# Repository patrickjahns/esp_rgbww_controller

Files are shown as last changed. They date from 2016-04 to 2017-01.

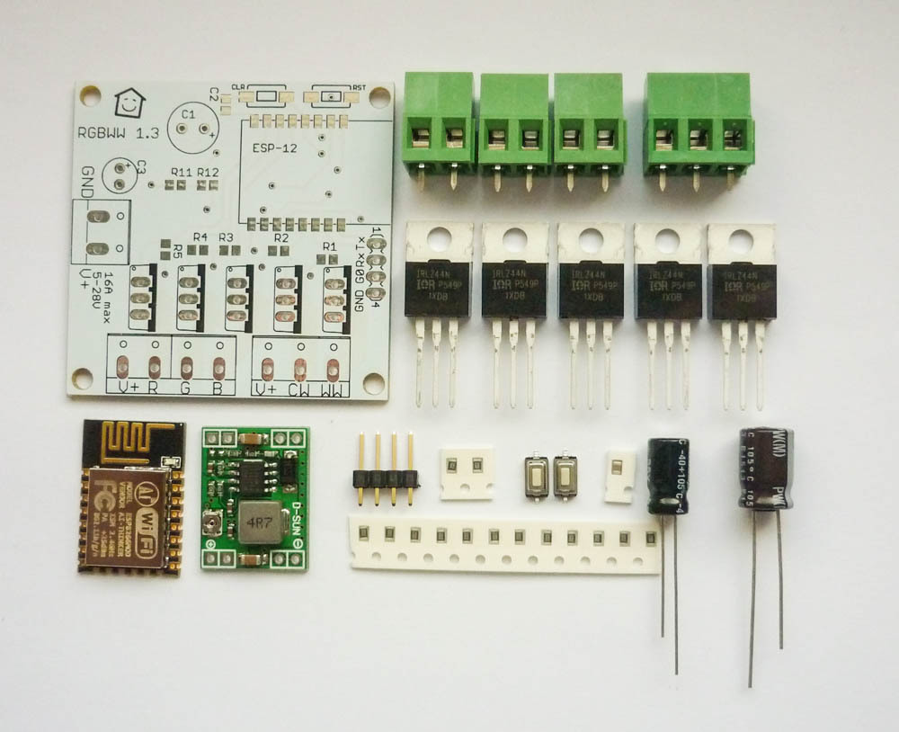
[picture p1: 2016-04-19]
pictures/rgbww-parts.jpg

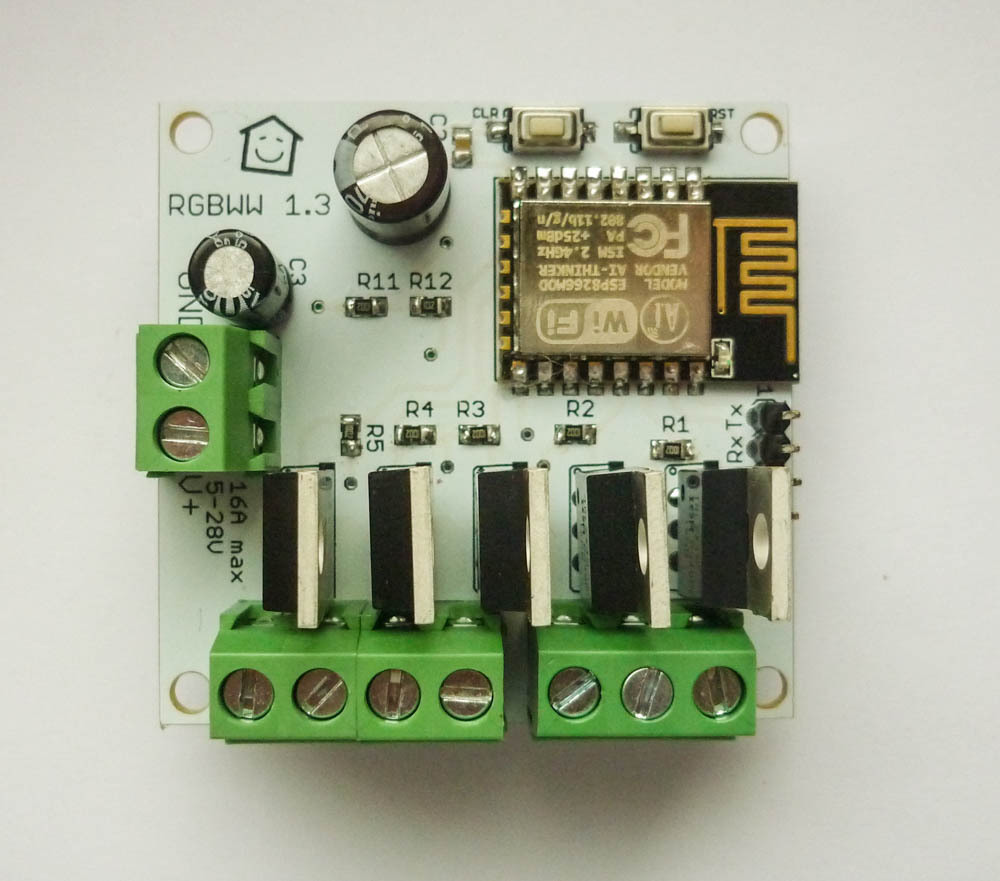
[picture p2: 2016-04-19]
pictures/rgbww-top-finished.jpg

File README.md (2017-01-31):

# ESP8266 WiFi RGBWW LED Dimmer v1.5
Custom Hardware board for controlling 5 Led Channels via PWM (RGB + Warm/Cold White). It is designed for max current ~4.5A per Channel.

# Changelog

* 1.5 (31.01.2017)
  * DCDC wandler has been remeasured and provided for through hole mounting on pin headers
  * Jumper introduced for allowing for external 3,3V connections
  * measurements have been changed to 53mm*47mm with mounting holes tailored towards "Strapubox CO 4" casing
  * C1 has been replaced with a smaller form factor

* 1.3 (20.02.2016)
  * added another tact switch which can be used during boot to reset settings
  * silksceen naming updated 

* 1.2 (16.02.2016)
  * improved the layout for better EMV
  * added buffer capacitor for dc converter
  * added filter capacitor close to ESP8266
  
* 1.1 (01.02.2016)
  * connected ADC 
  * some layout improvements

# Parts
- 1x ESP8266, ESP-12 format
- 1x XM1584 Power converter (set to 3.3v!)
- 5x IRLZ44N Mosfet (logic level gate threshold)
- 11x 10k resistors, 0805 (R1 - R11)
- 1x 1k resistors, 0805 (R12)
- 1x 330 µF Elko RM 2.5 mm (C1) 
- 1x 100 µF Elko RM 2.5 mm (C3)
- 1x 100 nF capacitor 0805(C2)
- 3x 5,08mm 2pin terminal block
- 1x 5,08mm 3pin terminal block
- 1x 2,54mm 4pin header
- 2x Micro SMD Tact Switch 2 pin 3*6*2.5 mm (optional)

# Assembly
Assembly of the PCB Board is straight forward, solder all parts to the PCB.

__Caution :__ before soldering the esp module to the PCB, set the output voltage of XM1584 converter  to 3.3v

### Recommended steps
- Start with soldering the smd resistors
- __Ensure the output voltage of XM1584 converter is 3.3v before continuing__. 
- Solder the XM1584 Power Board 
- Solder ESP8266 Module 
- Optional: solder SMD Tact Switch
- Solder Elkos
- Solder Terminal Blocks, 4pin header 
- Solder FETs

# Firmware
Firmware is still work in progress.

Latest can be found here:
https://github.com/patrickjahns/esp_rgbww_controller_fw

# Modifying
The schematic and board files are compatible with eagle 7.2+

## Ideas
Here are some ideas for future revisions
- see if we can clear some GPIOs and provide them via PIN Header for other enhancements (i.e. IR / Rotary Controller) 
- change layout for VCC/GND to be on the left side
- ~~connect ADC to detect power failure~~ 

# Resources
* [ESP RGB Project](https://github.com/RiRomain/esp-dimmer-hardware)
* [H801 Wifi Controller Hack](http://chaozlabs.blogspot.de/2015/08/esp8266-in-wild-wifi-led-controller-hack.html)

# Thread in Fhem Forum
* [Entwicklung/Sammelbestellung RGBWW Wifi Led Controller](https://forum.fhem.de/index.php/topic,48918.msg)

# Credits
Thanks to RiRomain for his excellent documentated [ESP RGB Project](https://github.com/RiRomain/esp-dimmer-hardware)

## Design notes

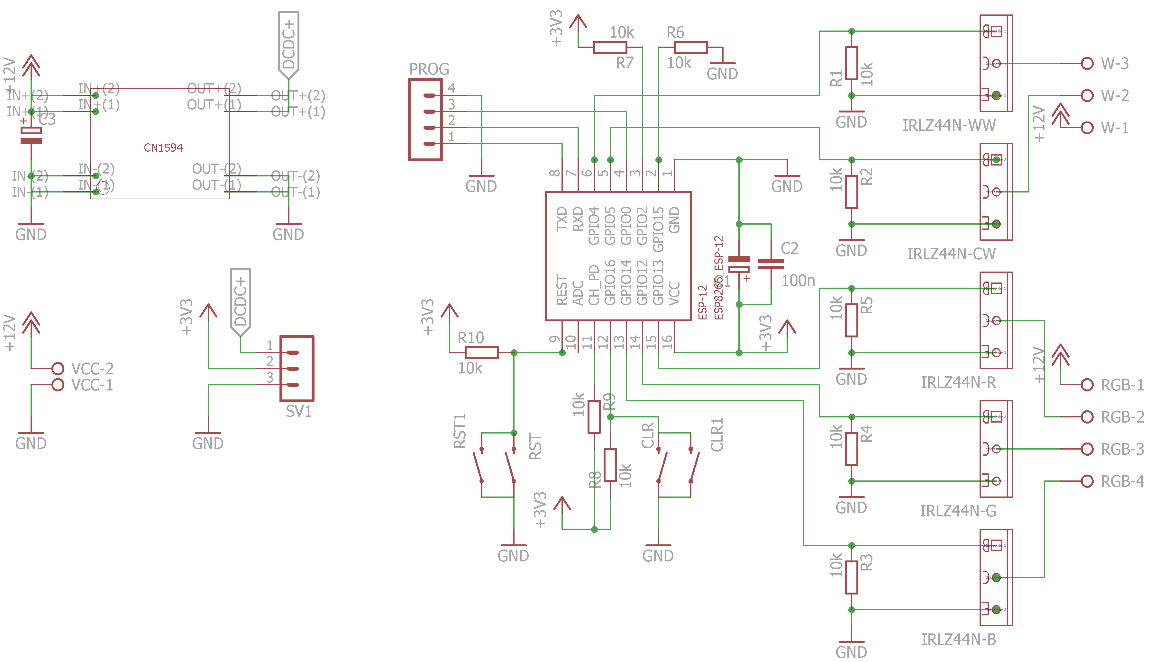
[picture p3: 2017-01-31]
pictures/schematics.png

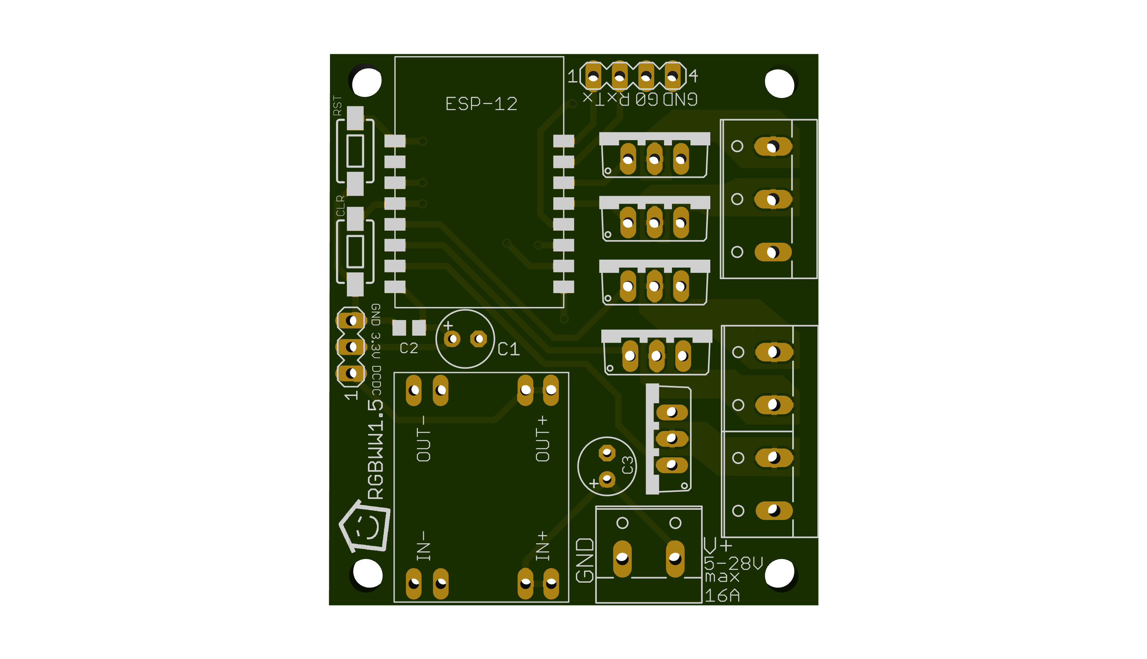
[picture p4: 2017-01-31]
pictures/render_top.png

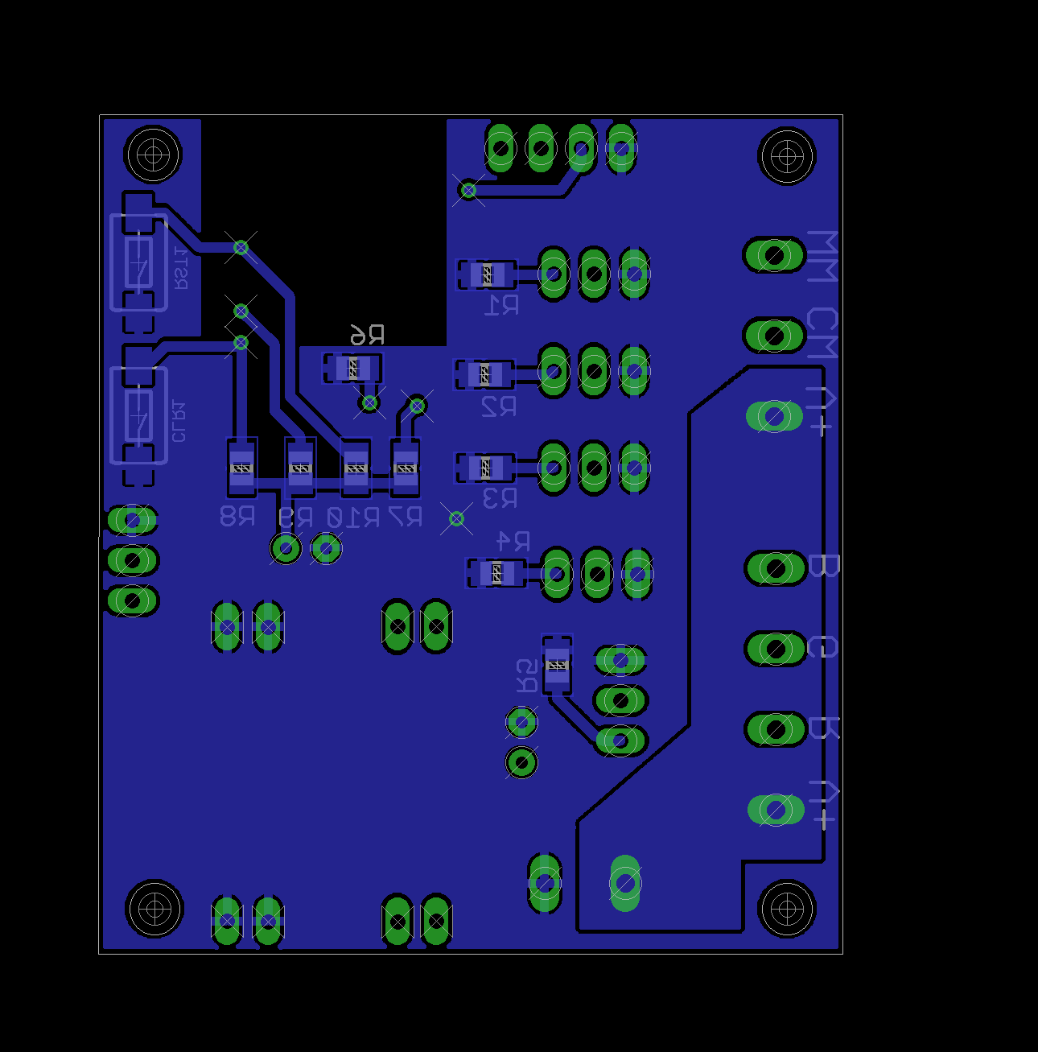
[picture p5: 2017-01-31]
pictures/eagle_bottom.png

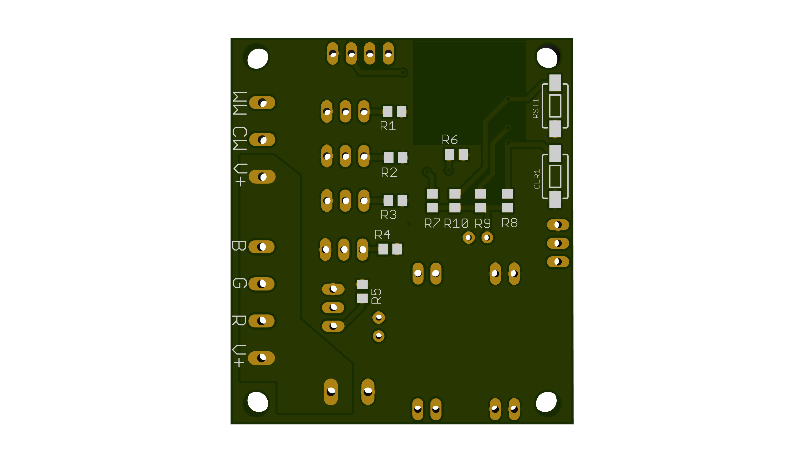
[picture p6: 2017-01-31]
pictures/render_bottom.png

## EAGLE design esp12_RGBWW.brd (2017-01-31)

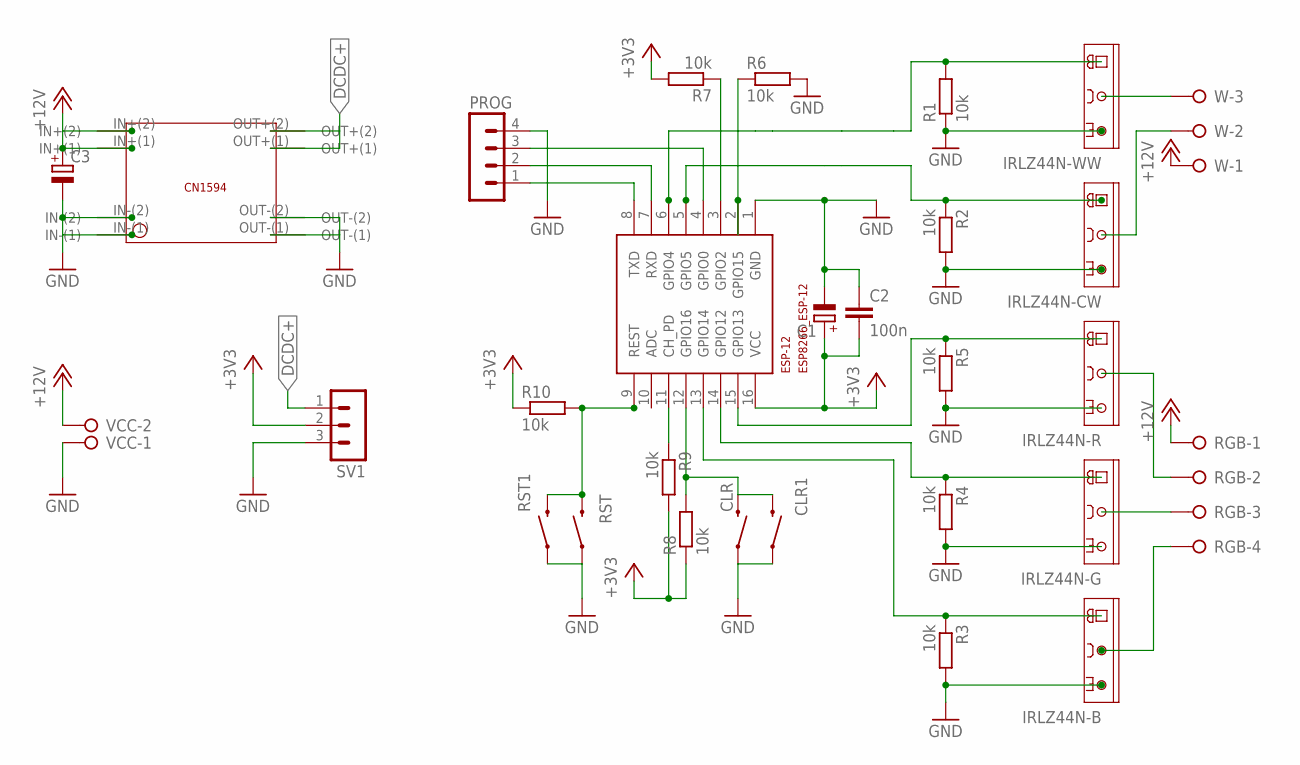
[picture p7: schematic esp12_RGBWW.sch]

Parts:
C1, C3: CPOL-EUE2.5-6; E2,5-6
C2: 100n; C0805
CLR, CLR1: SWITCH-MOMENTARY-2SMD-1101NE; TACTILE-SWITCH-1101NE
ESP-12: ESP8266_ESP-12; ESP8266-ESP12
IRLZ44N-B, IRLZ44N-CW, IRLZ44N-G, IRLZ44N-R, IRLZ44N-WW: TIP121; TO220AV
PROG: MA04-1
R1, R2, R3, R4, R5, R6, R7, R8, R9, R10: 10k; R0805
RGB: W237-04P; W237-4P
RST, RST1: SWITCH-MOMENTARY-2SMD-1101NE; TACTILE-SWITCH-1101NE
SV1: MA03-1
U$2: XM1584; XM1584-TH
VCC: W237-02P; W237-132
W: W237-03P; W237-133

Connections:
+3V3: C1.+, C2.2, ESP-12.16 (VCC), R7.2, R8.1, R9.2, R10.1, SV1.2
+12V: C3.+, RGB.1, U$2.IN+(1), U$2.IN+(2), VCC.2, W.1
DCDC+: SV1.1, U$2.OUT+(1), U$2.OUT+(2)
GND: C1.-, C2.1, C3.-, CLR.1, CLR1.1, ESP-12.1 (GND), IRLZ44N-B.E, IRLZ44N-CW.E, IRLZ44N-G.E, IRLZ44N-R.E, IRLZ44N-WW.E, PROG.4, R1.1, R2.2, R3.2, R4.2, R5.2, R6.2, RST.1, RST1.1, SV1.3, U$2.IN-(1), U$2.IN-(2), U$2.OUT-(1), U$2.OUT-(2), VCC.1
unnamed: CLR.2, CLR1.2, ESP-12.12 (GPIO16), R8.2
unnamed: ESP-12.11 (CH_PD), R9.1
unnamed: ESP-12.3 (GPIO2), R7.1
unnamed: ESP-12.7 (RXD), PROG.2
unnamed: ESP-12.2 (GPIO15), R6.1
unnamed: ESP-12.8 (TXD), PROG.1
unnamed: ESP-12.4 (GPIO0), PROG.3
unnamed: ESP-12.9 (REST), R10.2, RST.2, RST1.2
RGB-B: ESP-12.13 (GPIO14), IRLZ44N-B.B, R3.1
RGB-B-OUT: IRLZ44N-B.C, RGB.4
RGB-CW: ESP-12.5 (GPIO5), IRLZ44N-CW.B, R2.1
RGB-CW-OUT: IRLZ44N-CW.C, W.2
RGB-G: ESP-12.14 (GPIO12), IRLZ44N-G.B, R4.1
RGB-G-OUT: IRLZ44N-G.C, RGB.3
RGB-R: ESP-12.15 (GPIO13), IRLZ44N-R.B, R5.1
RGB-R-OUT: IRLZ44N-R.C, RGB.2
RGB-WW: ESP-12.6 (GPIO4), IRLZ44N-WW.B, R1.2
RGB-WW-OUT: IRLZ44N-WW.C, W.3

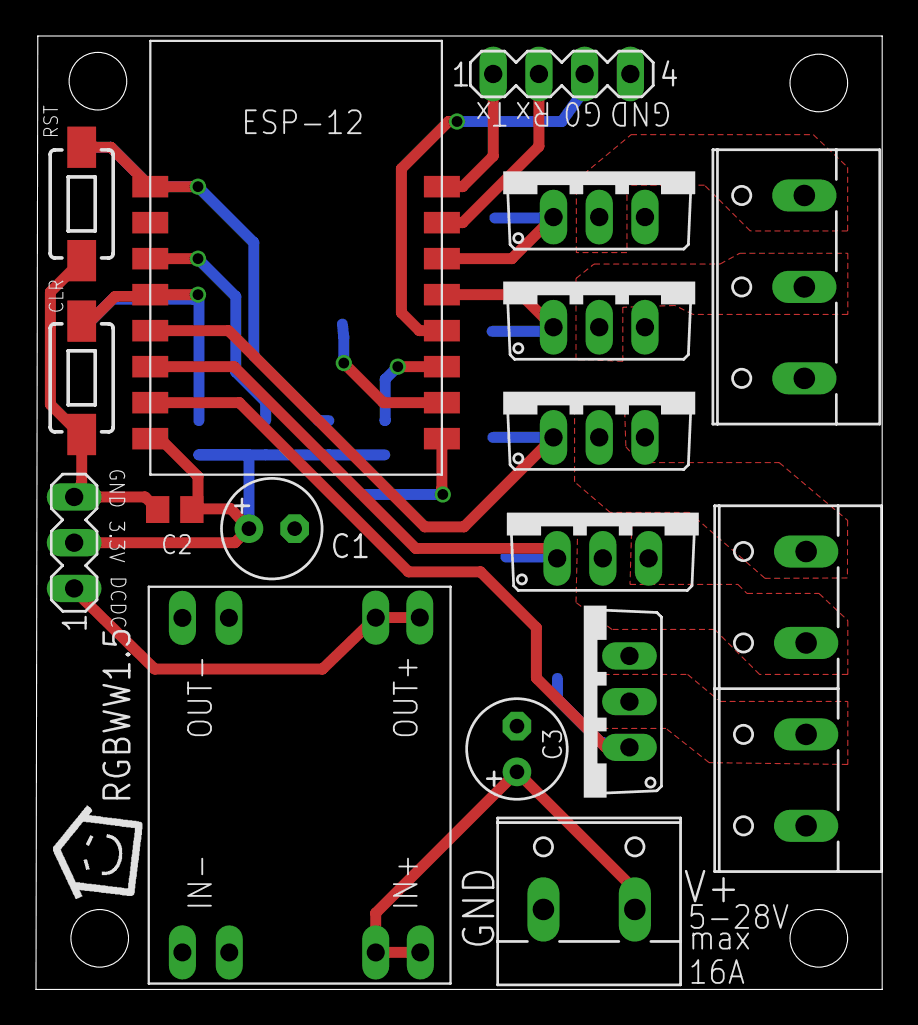
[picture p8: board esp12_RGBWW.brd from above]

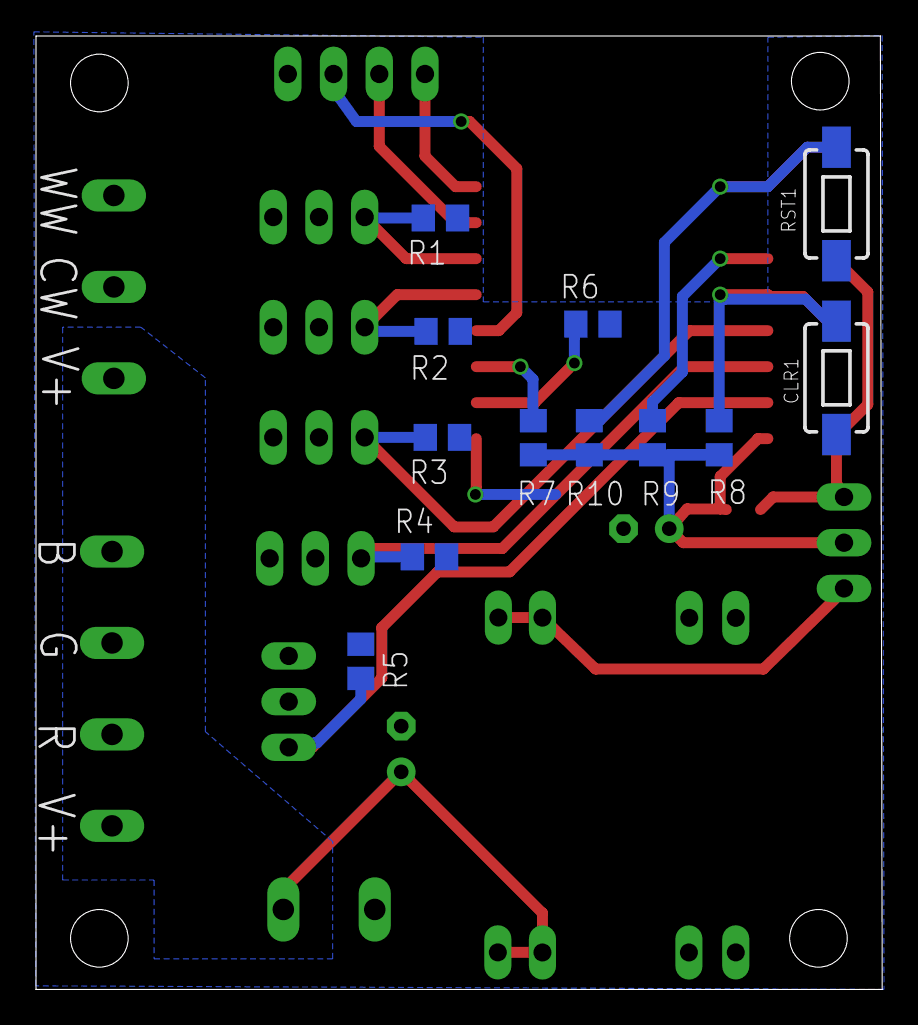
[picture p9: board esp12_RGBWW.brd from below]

Board: 2 copper layers, 47.0 x 53.0 mm, 30 parts (12 on the bottom side), 22 nets.

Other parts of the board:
U$1: LOGO

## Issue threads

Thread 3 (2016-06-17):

power pads not fully connected

pljakobs, 2016-06-17:
I would appreciate when all pads for the power supply module were connected. When I hand soldered the first controller, the inner ground pad on the 3.3V side of my module did not quite make contact - the outer one did. Troubleshoting took a bit but eventually I routed a wire to the gnd pin on the programming header and the whole thing worked.

patrickjahns, 2017-01-31:
Is solved in v1.5

Closed 2017-01-31.

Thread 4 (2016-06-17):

silkscreen

pljakobs, 2016-06-17:
when the board is fully populated, the silk screen markers for the output channels aren't visible anymore.

patrickjahns, 2017-01-31:
silk screen for channels is now moved to bottom in v1.5

Closed 2017-01-31.

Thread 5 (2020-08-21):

VCC des ESP zu gering

toblie, 2020-08-21:
Hi,
Ich habe eure Platine mal nachgebaut und wollte jetzt den ESP flashen...
Doch leider bekomme ich sie nicht betriebsbereit.

An den VCC und GND Stiften (3er Leiste) bekomme ich saubere 3,3v. Der Spannungsregler ist also korrekt eingestellt.
Wenn ich aber direkt an den VCC und GND pins des ESP messe, kommen nur noch knappe 0,4v an.

Kann sich das jemand erklären?
Habe ich irgendeinen Denk- oder Lötfehler?
Anbei mal Fotos des Aufbaus.

Über eine Rückmeldung würde ich mich freuen!
LG
Tobi
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

pljakobs, 2020-08-21:
Moin,
bei der Version ist der Ausgang des DCDC Wandler (iirc) der mittlere pin des dreifach Stiftleiste, der Eingang des ESP der daneben. Die Idee dabei ist, dass Du den Spannungswandler in Place einstellen kannst ohne den Rest der Schaltung durch Überspannung zu gefährden. Wenn der dann richtig eingestellt ist, dann kannst Du die 3,3V auf den ESP rüber jumpern.

Nebenbei hätte es eine neuere Version der Platine hier gegeben: https://github.com/pljakobs/esp_rgbww_controller/tree/v3.0

Grüße,

pj

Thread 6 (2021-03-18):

High Amperage use

borodamd, 2021-03-18:
Hi. You made an great scheme, but i want to put about 20m strip to this controller. It will take about 25 ampers, but as i understand, maximum load is 4a.

What i need to change in this scheme to use this load?
Thanks

pljakobs, 2021-03-18:
hey @borodamd, I have created a newer version of this board here https://github.com/pljakobs/esp_rgbww_controller/tree/Feature-externalGPIO-pmue.
This isn't optimized for high currents, and I would in general not advise you to plan for high currents. Why? because the strips are usually not designed for such high currents. I'm currently running a strip that is about 9m long at, at full RGBW load, draws about 6.5A, but at that load, you can already see a clear discoloration at the far end.
If you need to provide 20m, I would suggest to break that down into four strips of 5m ea.
There is a refactored firmware available that provides mqtt based synchronization between multiple controllers, see here https://github.com/verybadsoldier/esp_rgbww_firmware/wiki

I think such a setup would give you more reliability and flexibility. Also, I would suggest to consider running 24V strips (six per LED group rather than three) which will half your current requirement and make the whole design a lot more easy. You might then get away with two controllers.

pj

borodamd, 2021-03-18:
Thanks for advices. I already use strips 24v, but put separate RGB and CWW strips. But put line to separate controllers and sync them is good point. Also i planning to make firmware at ESPHome. It will be more flexible and sync from it will not be a problem.

Thanks again

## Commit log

2016-02-02 updated board
    [esp12_RGBWW.brd]
2016-02-02 added gerber files
    [esp12_RGBWW.GBL, esp12_RGBWW.GBO, esp12_RGBWW.GBP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]
2016-02-05 added ADC and updated board layout
    [esp12_RGBWW.brd, esp12_RGBWW.sch]
2016-02-16 small cosmetic corrections
    [esp12_RGBWW.brd]
2016-02-16 MOSFET netclass renamed
    [esp12_RGBWW.brd, esp12_RGBWW.sch]
2016-02-20 added 3d pcb renderings
2016-03-04 updated silkscreen
    [esp12_RGBWW.brd, esp12_RGBWW.sch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]
2016-04-16 Update README.md
    Add link to fhem forum thread
2017-01-31 CN1594 library exchanged with a more specific xm1584 library which also features through hole mounting
2017-01-31 updated schematics and board v1.5
    [esp12_RGBWW.brd, esp12_RGBWW.sch]
2017-01-31 gerber files for layout 1.5
    [esp12_RGBWW.GBL, esp12_RGBWW.GBO, esp12_RGBWW.GBP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]

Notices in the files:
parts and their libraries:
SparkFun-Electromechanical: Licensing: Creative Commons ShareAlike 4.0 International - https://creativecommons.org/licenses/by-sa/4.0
